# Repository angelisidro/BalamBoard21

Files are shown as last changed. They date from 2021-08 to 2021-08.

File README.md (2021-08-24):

# Balam Board v2.1


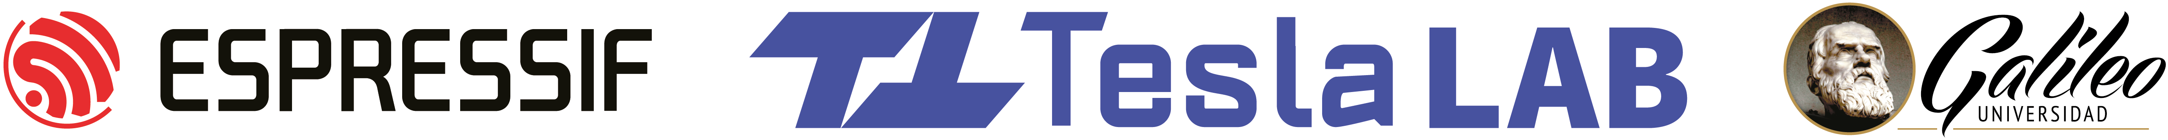
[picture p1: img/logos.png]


# Descripción del dispositivo

Shield para ESP32-WROOM Dev Kit, está tarjeta fue utilizada para la edición 2021 del Encuentro Nacional de Robótica BALAM. 

Este shield puede se diseño pensando en doble uso ya que el Encuentro Nacional de Robótica contó con dos distintos tracks, Internet de las Cosas y Robótica.

# Mapeo de Pines

## Balam Board V2.1 

### NeoPixel
Dispositivo | GPIO 
--- | --- 
NeoPixel 1 | 15 
NeoPixel 2 | 13 

### Buzzer
Dispositivo | GPIO 
--- | --- 
Buzzer | 27 

### Ultrasónico
Dispositivo | GPIO 
--- | --- 
VCC | 5V
GND | Ground
Trigger | 17
Echo | 16

### Comunicación I2C
Dispositivo | GPIO 
--- | --- 
VCC | 3V3
GND | Ground
SCL | 22
SDA | 21

### Comunicación SPI
Dispositivo | GPIO 
--- | --- 
VCC | 3V3
GND | Ground
CLK | 18
CS | 5
SDI | 19
SDO | 23

# Licencia

Hardware License: CERN OHL v1.0 para más información visitar el siguiente [Link][CERN_v1].

[CERN_v1]: https://ohwr.org/project/cernohl/wikis/Documents/CERN-OHL-version-1.2

Software License: GPL v3

Documentation License: CC BY 4.0 International

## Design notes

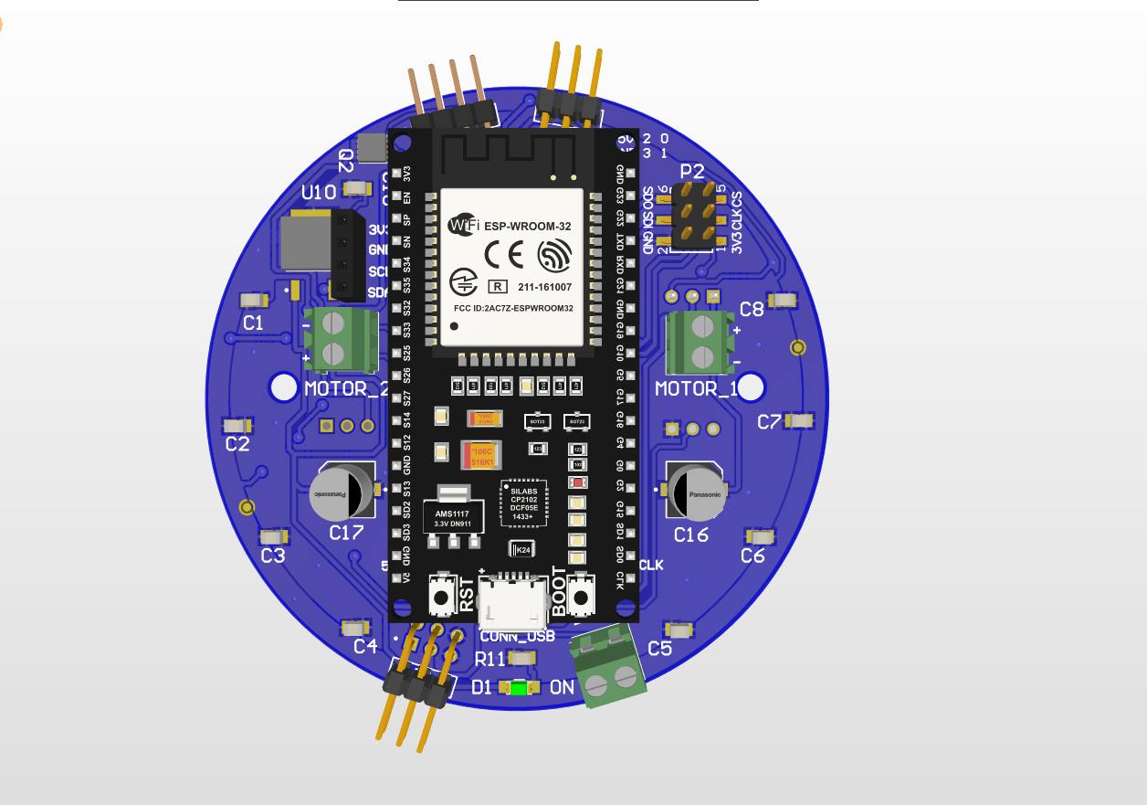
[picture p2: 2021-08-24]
hardware/Captura2.PNG

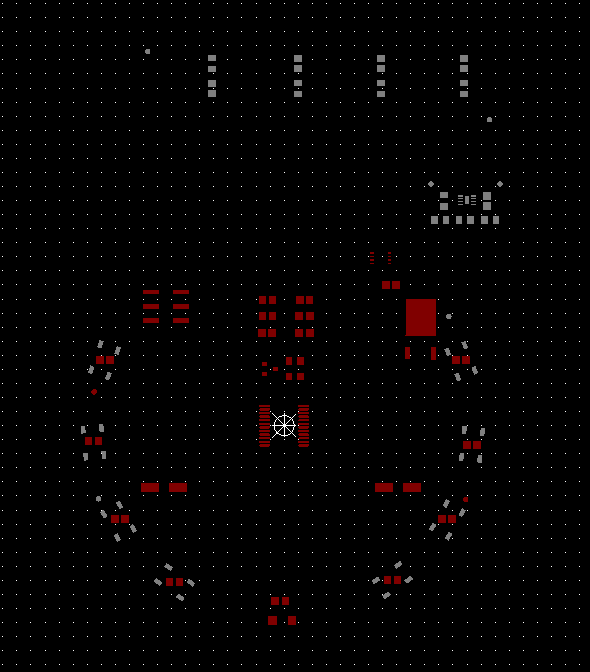
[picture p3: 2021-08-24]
hardware/Project Outputs for PCB_BALAM_21/TOP_Bottom PASTE.PNG

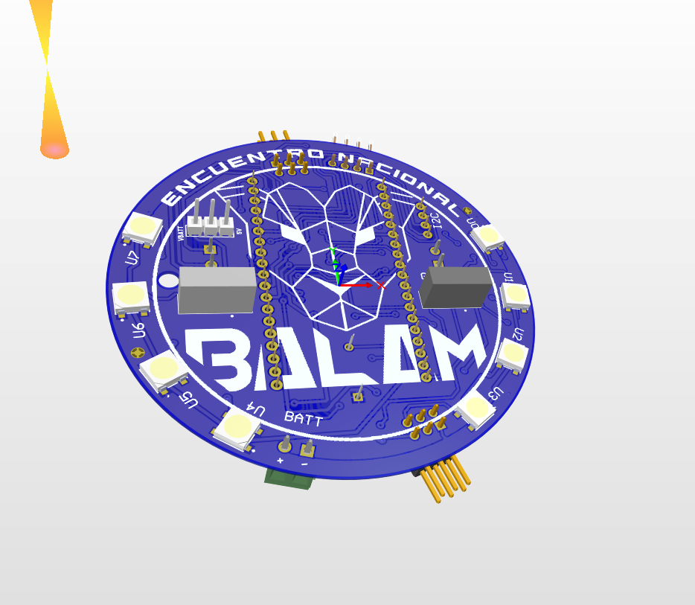
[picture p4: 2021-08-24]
hardware/Captura3.PNG

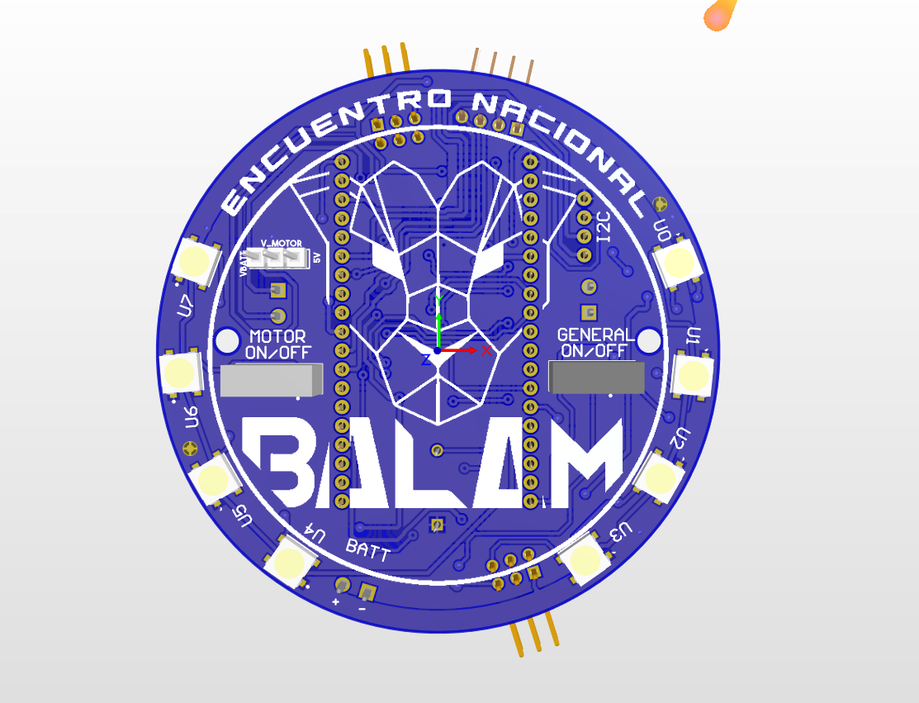
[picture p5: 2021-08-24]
hardware/Captura.PNG

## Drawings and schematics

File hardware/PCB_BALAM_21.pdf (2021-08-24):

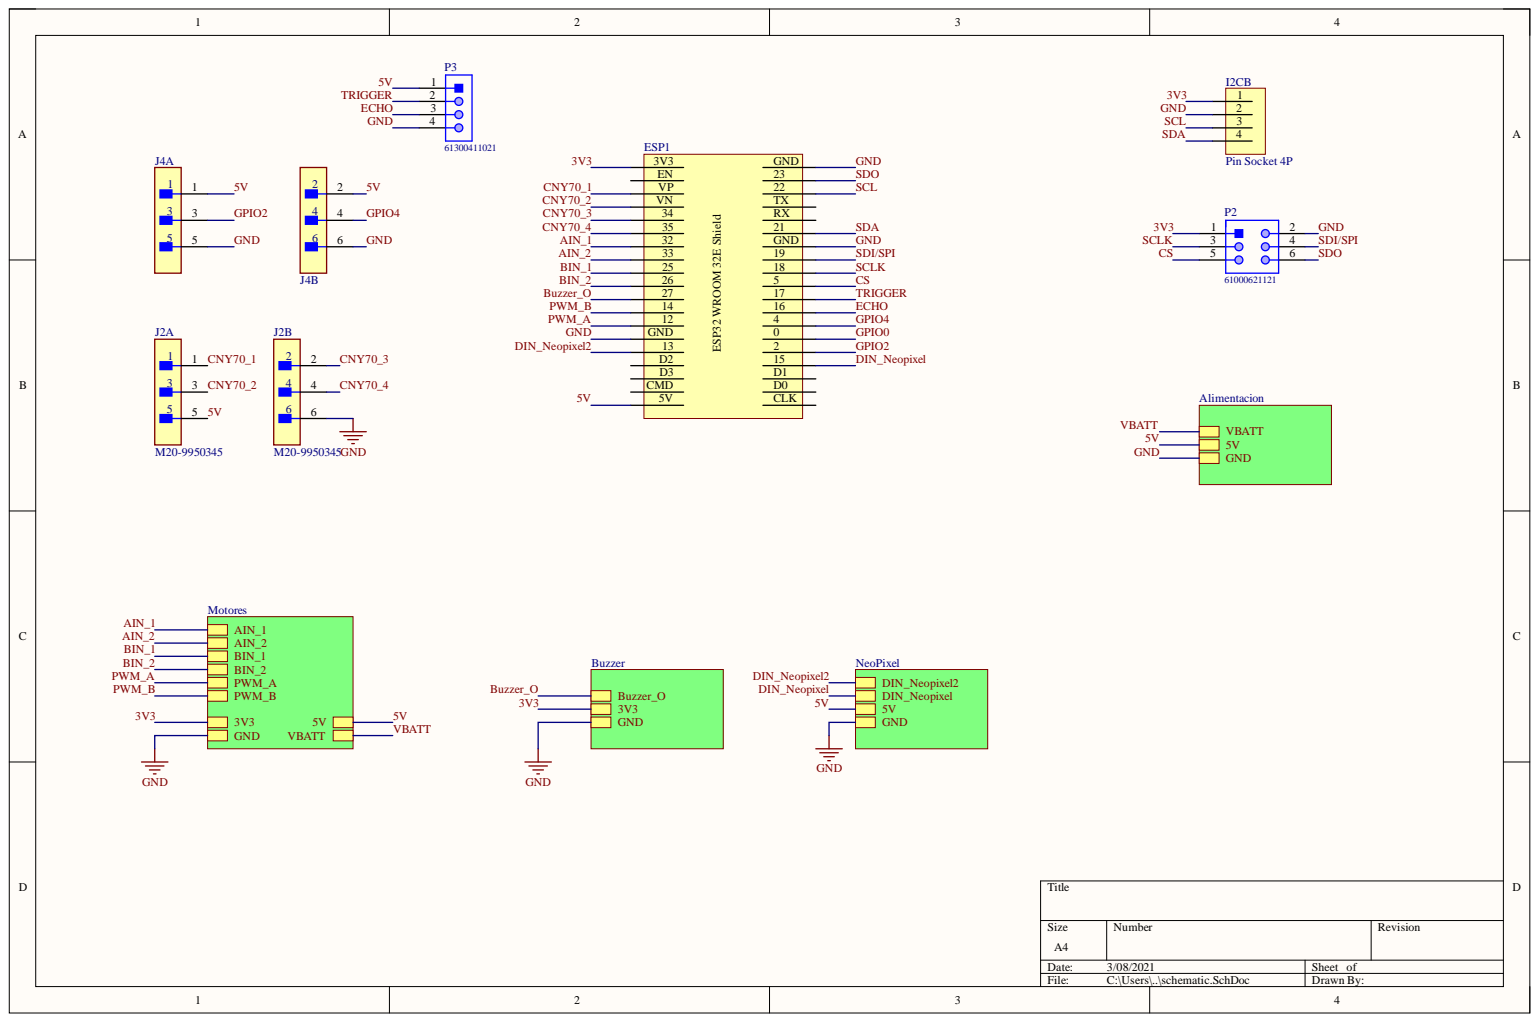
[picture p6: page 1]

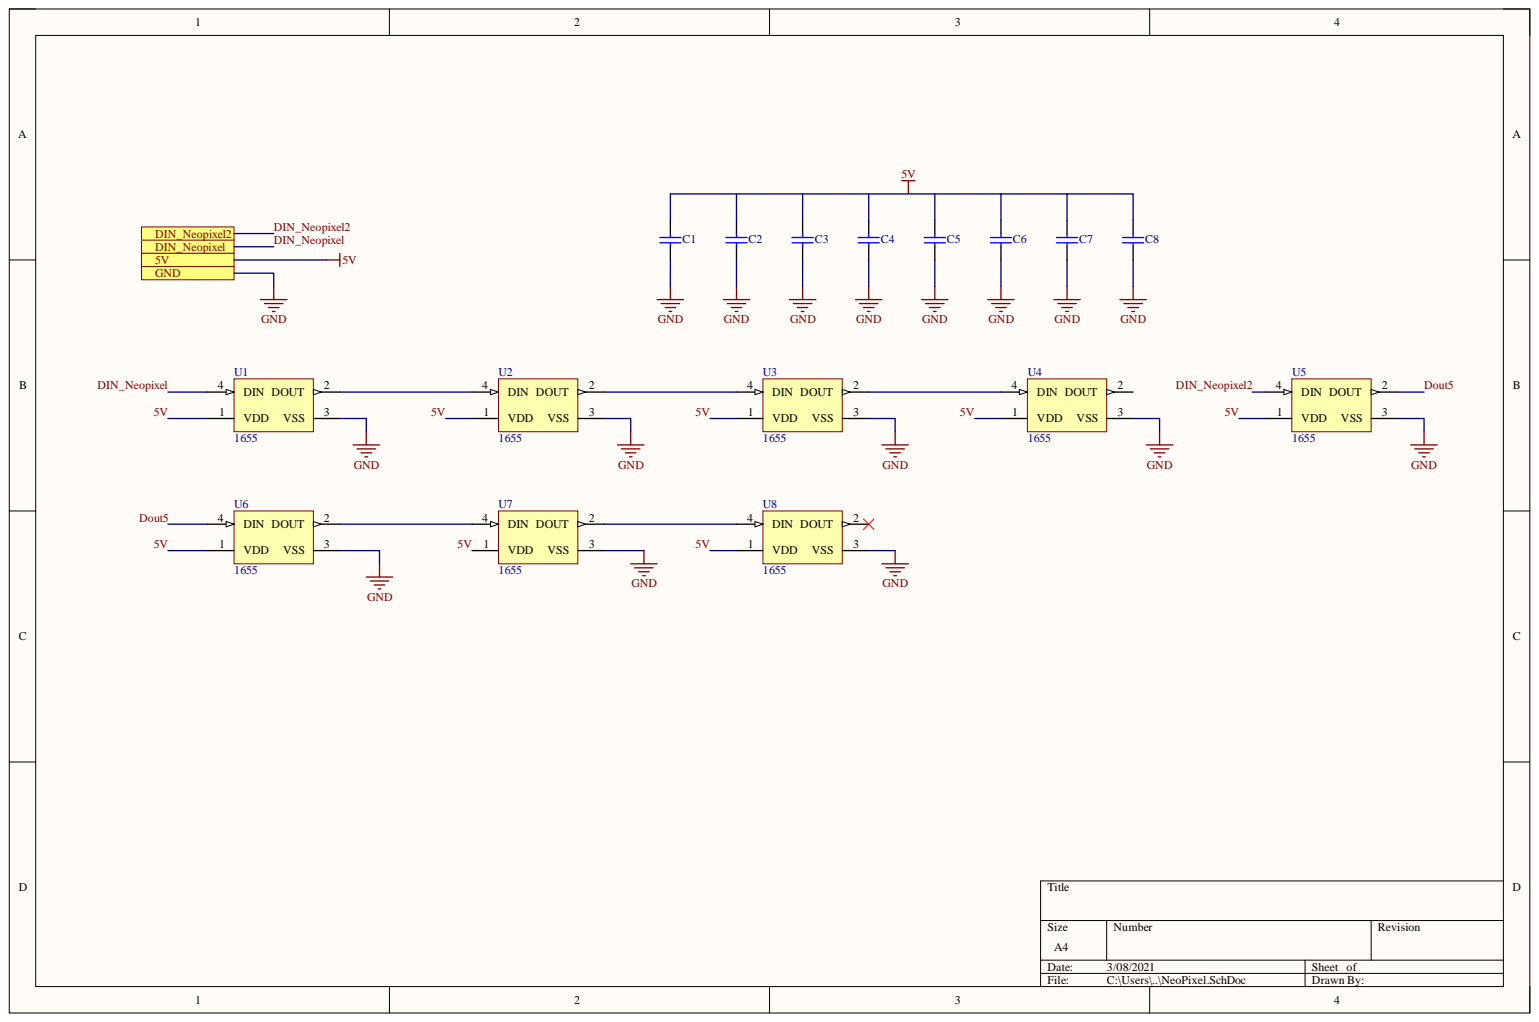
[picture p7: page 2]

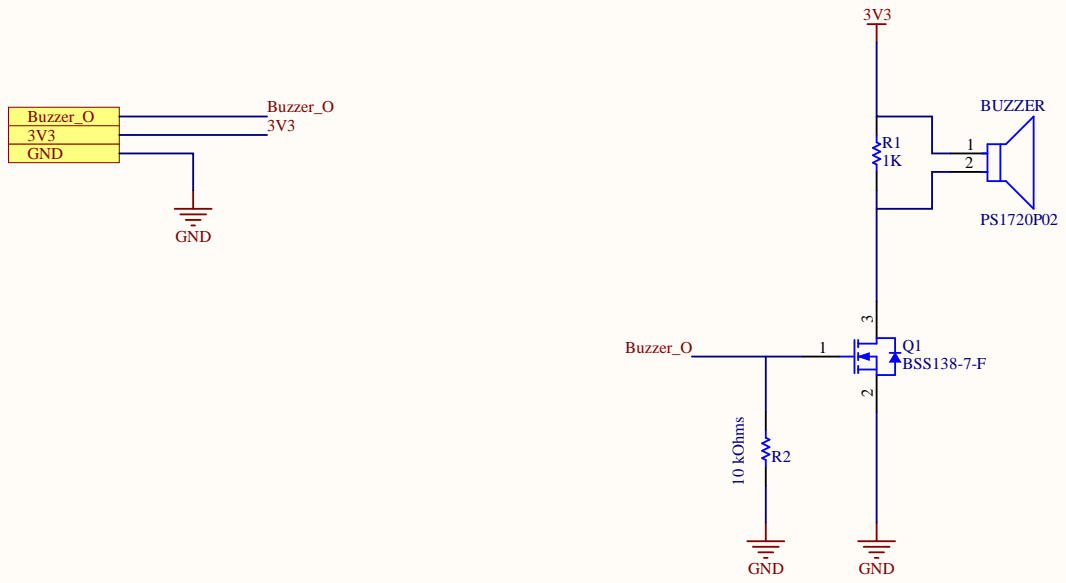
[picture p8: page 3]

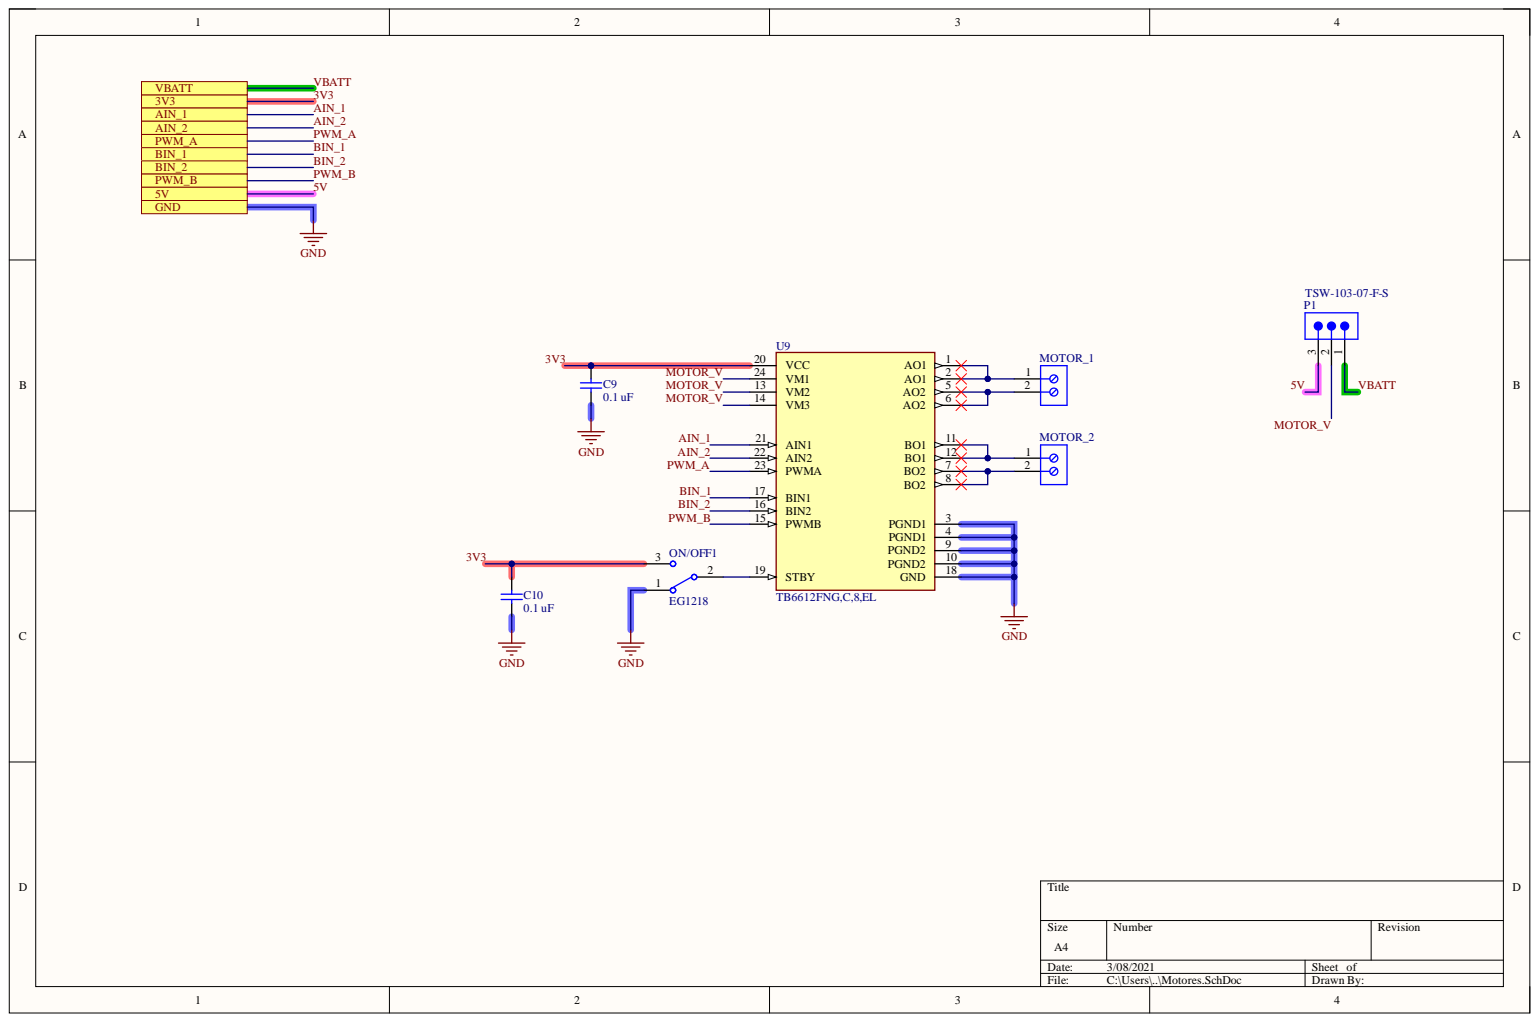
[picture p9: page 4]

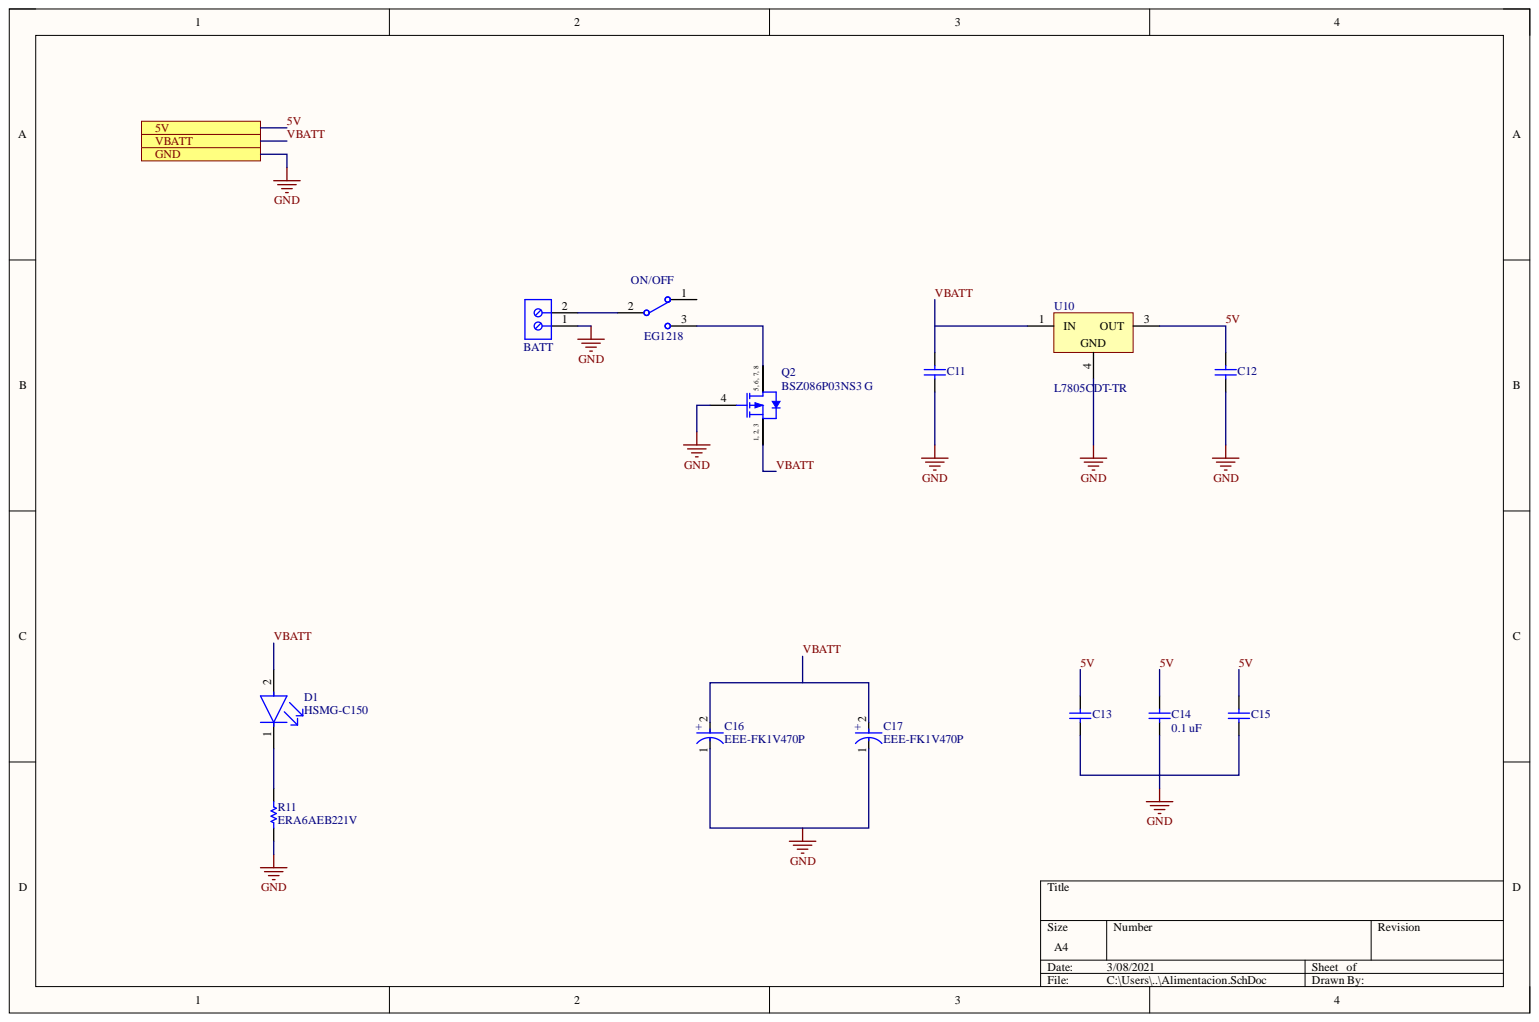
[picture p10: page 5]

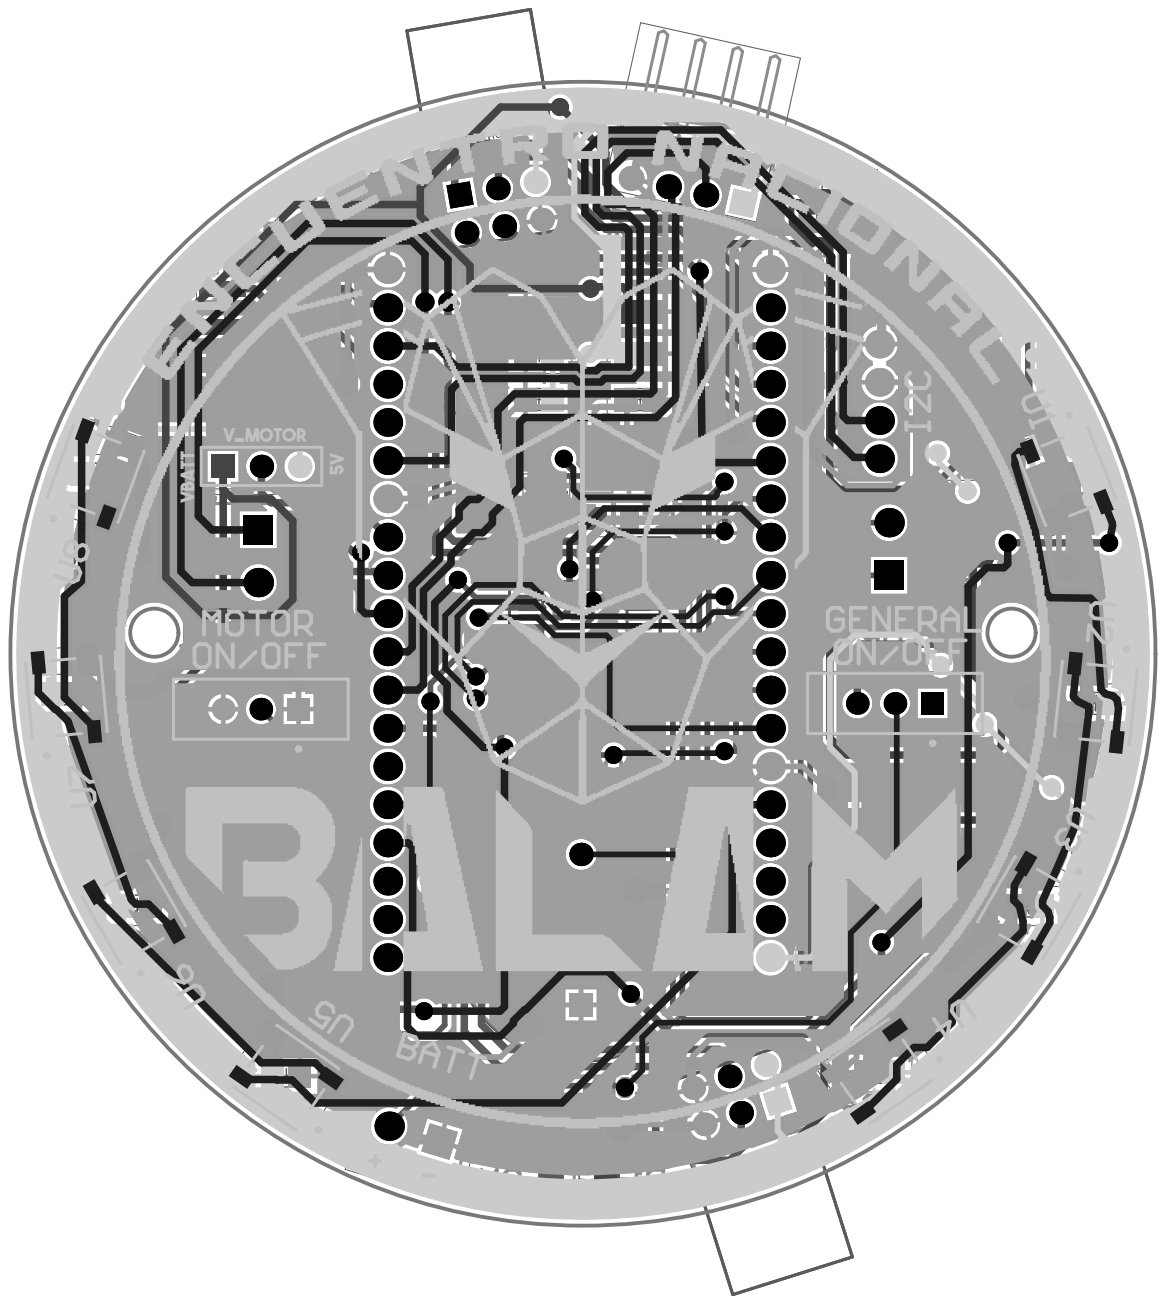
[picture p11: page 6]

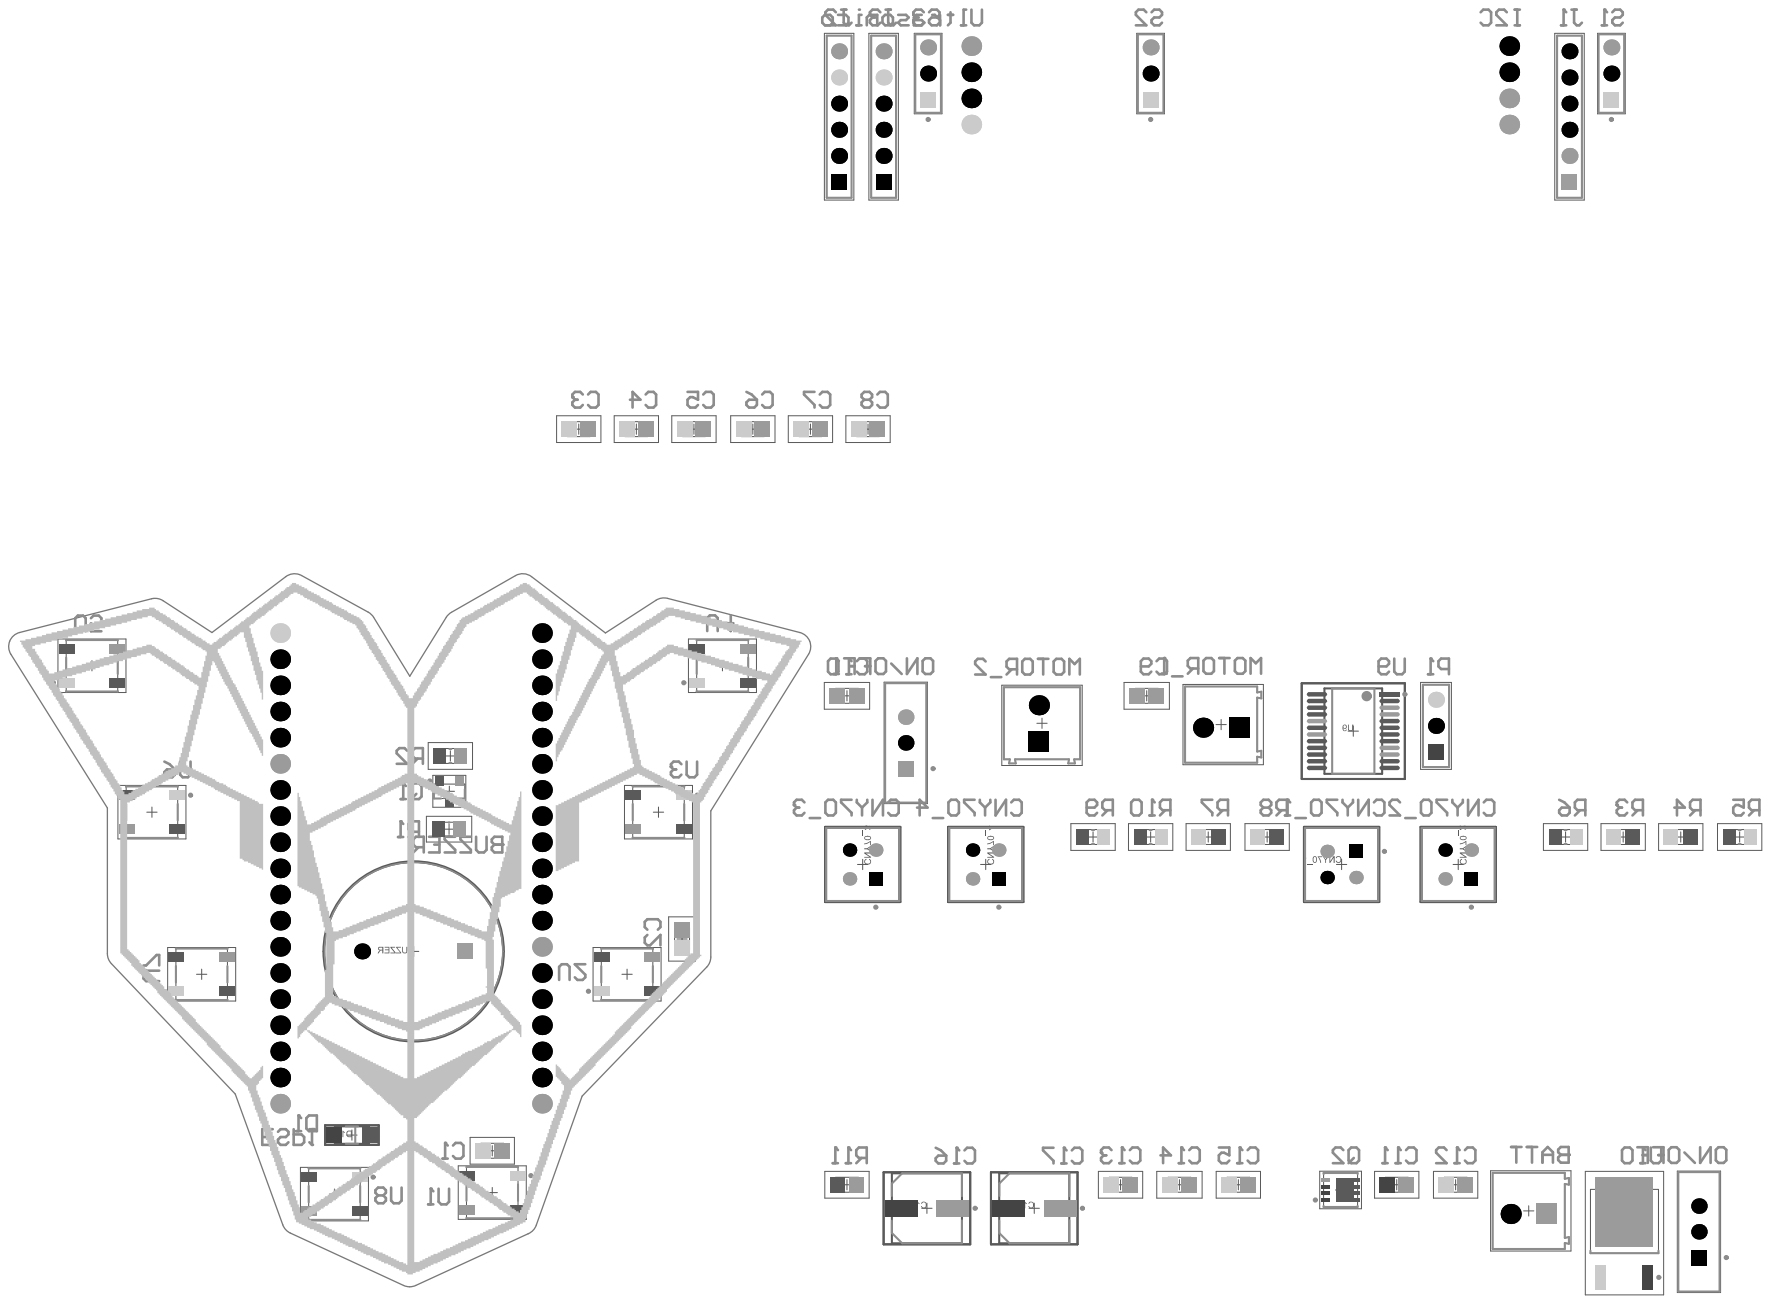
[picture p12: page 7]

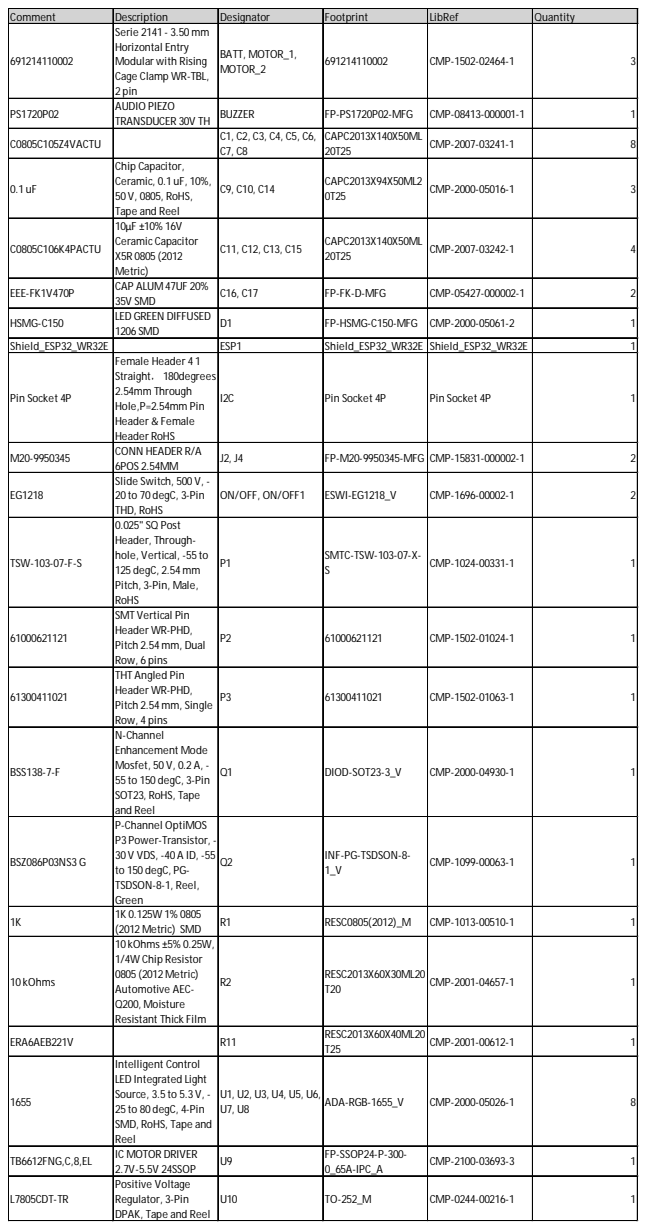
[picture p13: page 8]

Comment | Description | Designator | Footprint | LibRef | Quantity

Serie 2141 - 3.50mm Horizontal Entry Modular with Rising Cage Clamp WR-TBL, 2 pin | BATT, MOTOR_1, MOTOR_2 | 691214110002 | CMP-1502-02464-1 | 3

PS1720P02 | AUDIO PIEZO TRANSDUCER 30V TH | BUZZER | FP-PS1720P02-MFG | CMP-08413-000001-1 | 1

C0805C105Z4VACTU | | C1, C2, C3, C4, C5, C6, C7, C8 | CAPC2013X140X50ML 20T25 | CMP-2007-03241-1 | 8

0.1 uF | Chip Capacitor, Ceramic, 0.1 uF, 10%, 50 V, 0805, RoHS, Tape and Reel | C9, C10, C14 | CAPC2013X94X50ML2 0T25 | CMP-2000-05016-1 | 3

C0805C106K4PACTU | 10µF ±10% 16V Ceramic Capacitor X5R 0805 (2012 Metric) | C11, C12, C13, C15 | CAPC2013X140X50ML 20T25 | CMP-2007-03242-1 | 4

EEE-FK1V470P | CAP ALUM 47UF 20% 35V SMD | C16, C17 | FP-FK-D-MFG | CMP-05427-000002-1 | 2

HSMG-C150 | LED GREEN DIFFUSED 1206 SMD | D1 | FP-HSMG-C150-MFG | CMP-2000-05061-2 | 1

Shield_ESP32_WR32E | | ESP1 | Shield_ESP32_WR32E | Shield_ESP32_WR32E | 1
Pin Socket 4P | Female Header 4 1 Straight，180degrees 2.54mm Through Hole,P=2.54mm Pin Header & Female Header RoHS | I2C | Pin Socket 4P | Pin Socket 4P | 1

M20-9950345 | CONN HEADER R/A 6POS 2.54MM | J2, J4 | FP-M20-9950345-MFG | CMP-15831-000002-1 | 2

EG1218 | Slide Switch, 500 V, -20 to 70 degC, 3-Pin THD, RoHS | ON/OFF, ON/OFF1 | ESWI-EG1218_V | CMP-1696-00002-1 | 2

TSW-103-07-F-S | 0.025" SQ Post Header, Through-hole, Vertical, -55 to 125 degC, 2.54mm Pitch, 3-Pin, Male, RoHS | P1 | SMTC-TSW-103-07-X-S | CMP-1024-00331-1 | 1

61000621121 | SMT Vertical Pin Header WR-PHD, Pitch 2.54mm, Dual Row, 6 pins | P2 | 61000621121 | CMP-1502-01024-1 | 1

61300411021 | THT Angled Pin Header WR-PHD, Pitch 2.54mm, Single Row, 4 pins | P3 | 61300411021 | CMP-1502-01063-1 | 1

BSS138-7-F | N-Channel Enhancement Mode Mosfet, 50 V, 0.2 A, -55 to 150 degC, 3-Pin SOT23, RoHS, Tape and Reel | Q1 | DIOD-SOT23-3_V | CMP-2000-04930-1 | 1

BSZ086P03NS3 G | P-Channel OptiMOS P3 Power-Transistor, -30 V VDS, -40 A ID, -55 to 150 degC, PG-TSDSON-8-1, Reel, Green | Q2 | INF-PG-TSDSON-8-1_V | CMP-1099-00063-1 | 1

1K | 1K 0.125W 1% 0805 (2012 Metric) SMD | R1 | RESC0805(2012)_M | CMP-1013-00510-1 | 1

10 kOhms | 10 kOhms ±5% 0.25W, 1/4W Chip Resistor 0805 (2012 Metric) Automotive AEC-Q200, Moisture Resistant Thick Film | R2 | RESC2013X60X30ML20 T20 | CMP-2001-04657-1 | 1

ERA6AEB221V | | R11 | RESC2013X60X40ML20 T25 | CMP-2001-00612-1 | 1

1655 | Intelligent Control LED Integrated Light Source, 3.5 to 5.3 V, -25 to 80 degC, 4-Pin SMD, RoHS, Tape and Reel | U1, U2, U3, U4, U5, U6, U7, U8 | ADA-RGB-1655_V | CMP-2000-05026-1 | 8

TB6612FNG,C,8,EL | IC MOTOR DRIVER 2.7V-5.5V 24SSOP | U9 | FP-SSOP24-P-300-0_65A-IPC_A | CMP-2100-03693-3 | 1

L7805CDT-TR | Positive Voltage Regulator, 3-Pin DPAK, Tape and Reel | U10 | TO-252_M | CMP-0244-00216-1 | 1
